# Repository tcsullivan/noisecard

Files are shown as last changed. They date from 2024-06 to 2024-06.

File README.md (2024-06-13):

# NoiseCard

NoiseCard is an attempt to build a dead easy tool for monitoring ambient noise levels. The ultra-low-power microcontroller takes periodic decibel measurements while powered on, using blinking LEDs for indication. The circuit requires only a few milliwatts to run, enabling it to run off of direct solar power without a battery (though some large capacitors provide a small reserve).

Ambient noise levels in populated areas, especially North America, can often exceed what is considered safe for our ears, with prolonged exposure leading to lasting impacts on our health. Through a tool like the NoiseCard, people can become more aware of the noisy environments they're living in (and potentially take action to reduce excess noise exposure).

## Building the source

You need:

* [ChibiOS sources](https://www.chibios.org/dokuwiki/doku.php)
* The arm-none-eabi GCC toolchain (through your distro or from [ARM developer](https://developer.arm.com/downloads/-/gnu-rm))
* [GNU Make](https://www.gnu.org/software/make/)
* [OpenOCD](https://openocd.org/) or another tool to program the microcontroller
* [KiCAD](https://www.kicad.org/) if you wish to work with the hardware files

Extract ChibiOS to a folder, edit the `Makefile` so CHIBIOS points to that folder, then run `make`.

### Flashing the card

You'll need a 6-pin Tag-Connect cable (e.g. [TC2030-CTX-NL](https://www.tag-connect.com/product/tc2030-ctx-nl-6-pin-no-legs-cable-with-10-pin-micro-connector-for-cortex-processors)), compatible programmer, and OpenOCD. Power up the card and run the following command (using the appropriate interface scripts for your programmer):

```
openocd -f interface/ftdi/olimex-arm-usb-ocd-h.cfg -f interface/ftdi/olimex-arm-jtag-swd.cfg -f target/stm32g0x.cfg -c "program build/ch.hex verify reset exit"
```

## Credits

* [ESP32-I2S-SLM](https://hackaday.io/project/166867-esp32-i2s-slm) for a starting point with accurate decibel-measuring code.
* [Qfplib](https://www.quinapalus.com/qfplib.html) for providing optimized floating-point code for the Cortex-M0+ microcontroller.
* ChibiOS for providing an awesome RTOS and HAL that made firmware porting and device configuration a breeze.

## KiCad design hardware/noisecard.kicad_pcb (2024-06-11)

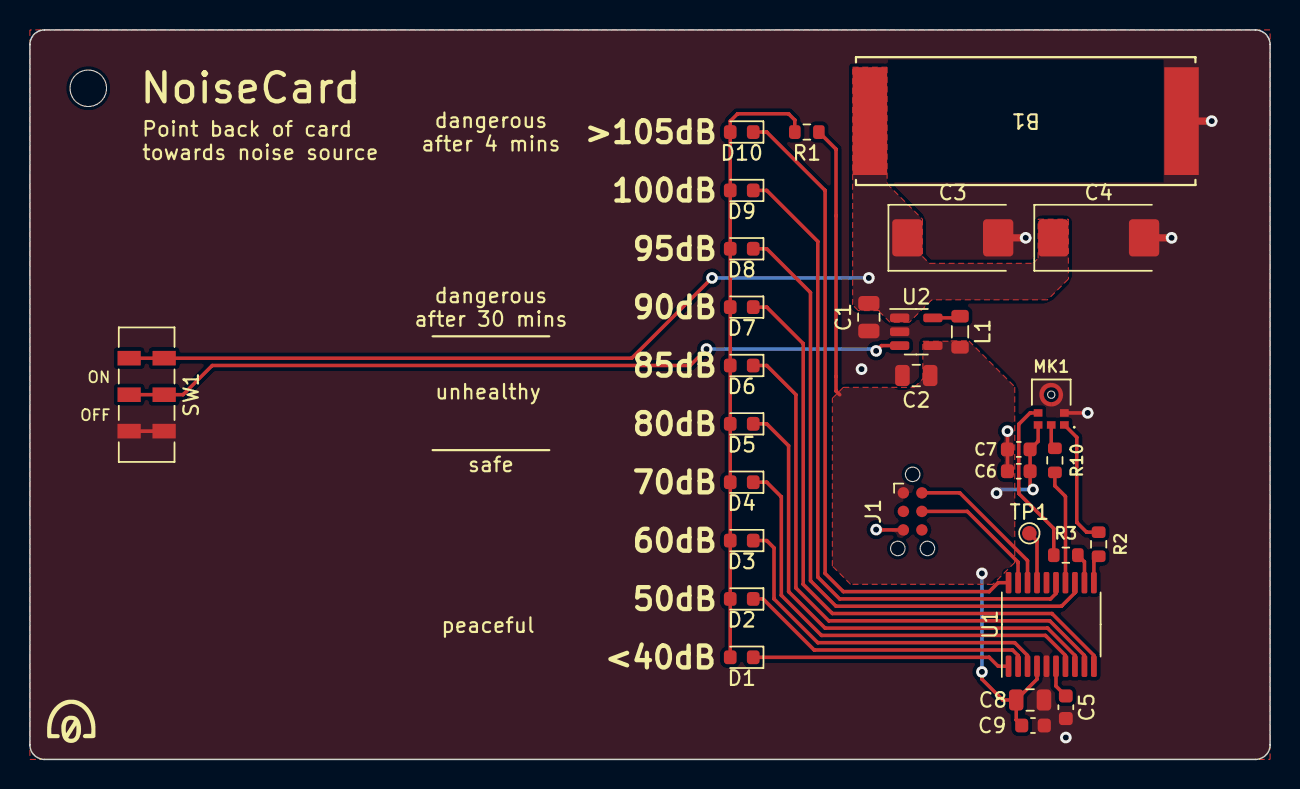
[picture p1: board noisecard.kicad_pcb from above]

Board: 2 copper layers, 85.0 x 50.0 mm, 32 parts (0 on the bottom side), 26 nets.

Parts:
B1: KXOB25-02X8F-TR; KXOB25-02X8F-TR_IXY
C1: 4u7; C_0805_2012Metric
C2: 10u; C_0805_2012Metric
C3, C4: 330u; CP_EIA-7343-15_Kemet-W
C5, C6, C9: 0.1U; C_0603_1608Metric
C7: 200P; C_0603_1608Metric
C8: 2U2; C_0805_2012Metric
D1, D2, D3, D4, D5, D6, D7, D8, D9, D10: LED; LED_0603_1608Metric
H1: MountingHole_Pad; MountingHole_2.5mm
J1: Conn_ARM_SWD_TagConnect_TC2030-NL; Tag-Connect_TC2030-IDC-NL_2x03_P1.27mm_Vertical
L1: 10u; L_0805_2012Metric
MK1: SPH0645LM4H-B; MIC_SPH0645LM4H-B
R1, R2, R3, R10: 51; R_0603_1608Metric
SW1: SW_DPDT_x2; SW_DPDT_CK_JS202011JCQN
TP1: TestPoint; TestPoint_Pad_D1.0mm
U1: STM32G031F6Px; TSSOP-20_4.4x6.5mm_P0.65mm
U2: LM3670MF; TSOT-23-5

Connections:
+1V8: C2.1, C6.1, C7.1, C8.1, C9.1, J1.1 (VCC), L1.2, MK1.5 (VDD), R1.1, U1.4 (VDD), U2.4 (FB)
EN: SW1.2 (B), SW1.5 (B), U2.3 (EN)
GND: B1.1, C1.2, C2.2, C3.2, C4.2, C5.2, C6.2, C7.2, C8.2, C9.2, J1.5 (GND), MK1.2 (SELECT), MK1.3 (GND), SW1.3 (C), SW1.6 (C), U1.5 (VSS), U2.2 (GND)
LED0: D1.1 (K), U1.1 (PB7/PB8)
LED1: D2.1 (K), U1.2 (PC14/PB9)
LED2: D3.1 (K), U1.3 (PC15)
LED3: D4.1 (K), U1.7 (PA0)
LED4: D5.1 (K), U1.8 (PA1)
LED5: D6.1 (K), U1.9 (PA2)
LED6: D7.1 (K), U1.10 (PA3)
LED7: D8.1 (K), U1.13 (PA6)
LED8: D9.1 (K), U1.15 (PB0/PB1/PB2/PA8)
LED9: D10.1 (K), U1.20 (PB3/PB4/PB5/PB6)
MIC_BCLK: MK1.4 (BCLK), R3.1
MIC_DATA_OUT: R10.2, U1.14 (PA7)
MIC_WS: MK1.1 (WS), R2.1
NRST: C5.1, U1.6 (PF2)
unnamed: D1.2 (A), D2.2 (A), D3.2 (A), D4.2 (A), D5.2 (A), D6.2 (A), D7.2 (A), D8.2 (A), D9.2 (A), D10.2 (A), R1.2
unnamed: MK1.6 (DATA_OUT), R10.1
unnamed: R2.2, U1.11 (PA4)
unnamed: R3.2, U1.12 (PA5)
unnamed: TP1.1, U1.17 (PA12/PA10)
unnamed: L1.1, U2.5 (SW)
SWCLK: J1.4 (SWCLK), U1.19 (PA14/PA15)
SWDIO: J1.2 (SWDIO), U1.18 (PA13)
VDC: B1.2, C1.1, C3.1, C4.1, SW1.1 (A), SW1.4 (A), U2.1 (Vin)

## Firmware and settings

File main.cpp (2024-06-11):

/**
 * Copyright (C) 2024  Clyne Sullivan <clyne@bitgloo.com>
 *
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
 * You should have received a copy of the GNU General Public License
 * along with this program.  If not, see <https://www.gnu.org/licenses/>.
 */
#include "hal.h"
#include "sos-iir-filter.h"

#include <algorithm>
#include <atomic>
#include <array>
#include <cstring>
#include <ranges>

static constexpr auto& WEIGHTING       = A_weighting;
static constexpr auto& MIC_EQUALIZER   = SPH0645LM4H_B_RB;
static constexpr sos_t MIC_OFFSET_DB   (  0.f); // Linear offset
static constexpr sos_t MIC_SENSITIVITY (-26.f); // dBFS value expected at MIC_REF_DB
static constexpr sos_t MIC_REF_DB      ( 94.f); // dB where sensitivity is specified
static constexpr sos_t MIC_OVERLOAD_DB (120.f); // dB - Acoustic overload point
static constexpr sos_t MIC_NOISE_DB    ( 29.f); // dB - Noise floor
static constexpr auto  MIC_BITS        = 18u;
static constexpr auto  SAMPLE_RATE     = 48000u;

static constexpr unsigned I2S_BUFSIZ = 1024;
static constexpr unsigned I2S_USESIZ = 16;

// Calculate reference amplitude value at compile time
static const auto MIC_REF_AMPL = sos_t((1 << (MIC_BITS - 1)) - 1) *
    qfp_fpow(10.f, MIC_SENSITIVITY / 20.f);

static std::atomic_bool i2sReady;
static std::array<uint32_t, I2S_BUFSIZ> i2sBuffer;
static sos_t Leq_sum_sqr (0.f);
static unsigned Leq_samples = 0;

static void blinkDb(int db);
static void i2sCallback(I2SDriver *i2s);

static constexpr unsigned I2SPRval = 16'000'000 / SAMPLE_RATE / 32 / 2;
static constexpr I2SConfig i2sConfig = {
    /* TX buffer */ NULL,
    /* RX buffer */ i2sBuffer.data(),
    /* Size */      i2sBuffer.size(),
    /* Callback */  i2sCallback,
    /* I2SCFGR */   (3 << SPI_I2SCFGR_I2SCFG_Pos) | // Master receive
                    (0 << SPI_I2SCFGR_I2SSTD_Pos) | // Philips I2S
                    (1 << SPI_I2SCFGR_DATLEN_Pos) | // 24-bit
                    SPI_I2SCFGR_CHLEN,              // 32-bit frame
    /* I2SPR */     (I2SPRval / 2) | ((I2SPRval & 1) ? SPI_I2SPR_ODD : 0)
};

int main(void)
{
    halInit();
    osalSysEnable();
  
    i2sReady.store(true);
    i2sStart(&I2SD1, &i2sConfig);
    i2sStartExchange(&I2SD1);
    // Microphone warmup time
    osalThreadSleepMilliseconds(140);
    // Reach filter delay steady state
    i2sReady.store(false);
    osalThreadSleepMilliseconds(120);
    // Discard initial readings
    Leq_sum_sqr = 0.f;
    Leq_samples = 0;

    for (;;) {
        i2sReady.store(false);
        SCB->SCR |= SCB_SCR_SLEEPONEXIT_Msk;
        //palClearLine(LINE_TP1);
        __WFI();
        //palSetLine(LINE_TP1);

        const auto sum_sqr = std::exchange(Leq_sum_sqr, sos_t(0.f));
        const auto count = std::exchange(Leq_samples, 0);
        const sos_t Leq_RMS = qfp_fsqrt(sum_sqr / qfp_uint2float(count));
        const sos_t Leq_dB = MIC_OFFSET_DB + MIC_REF_DB + sos_t(20.f) *
            qfp_flog10(Leq_RMS / MIC_REF_AMPL);
        const auto n = std::clamp(qfp_float2int(Leq_dB), 0, 999);
        blinkDb(n);
    }
}

void blinkDb(int db)
{
    auto line = LINE_LED0;

    if (db < 45)
        line = LINE_LED0;
    else if (db < 55)
        line = LINE_LED1;
    else if (db < 65)
        line = LINE_LED2;
    else if (db < 75)
        line = LINE_LED3;
    else if (db < 82)
        line = LINE_LED4;
    else if (db < 87)
        line = LINE_LED5;
    else if (db < 92)
        line = LINE_LED6;
    else if (db < 97)
        line = LINE_LED7;
    else if (db < 102)
        line = LINE_LED8;
    else
        line = LINE_LED9;

    palClearLine(line);
    osalThreadSleepMilliseconds(100);
    palSetLine(line);
}

__attribute__((section(".data")))
int32_t fixsample(uint32_t s) {
    return (int32_t)(((s & 0xFFFF) << 16) | (s >> 16)) >> (32 - MIC_BITS);
}

__attribute__((section(".data")))
void i2sCallback(I2SDriver *i2s)
{
    if (i2sReady.load())
        return;

    //palSetLine(LINE_TP1);

    const auto halfsize = i2sBuffer.size() / 2;
    const auto source = i2sBuffer.data() + (i2sIsBufferComplete(i2s) ? halfsize : 0);
    auto samples = reinterpret_cast<sos_t *>(source);
    std::ranges::copy(
        std::views::counted(source, I2S_USESIZ * 2)
            | std::ranges::views::stride(2)
            | std::views::transform([](uint32_t s) { return sos_t(qfp_int2float_asm(fixsample(s))); }),
        samples);
    auto samps = std::views::counted(samples, I2S_USESIZ);

    // Accumulate Leq sum
    MIC_EQUALIZER.filter(samps);
    Leq_sum_sqr += WEIGHTING.filter_sum_sqr(samps);
    Leq_samples += halfsize / 2;

    // Wakeup main thread for dB calculation every half second
    if (Leq_samples >= SAMPLE_RATE / 2) {
        i2sReady.store(true);
        SCB->SCR &= ~SCB_SCR_SLEEPONEXIT_Msk;
    }

    //palClearLine(LINE_TP1);
}

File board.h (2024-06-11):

/*
    ChibiOS - Copyright (C) 2006..2020 Giovanni Di Sirio

    Licensed under the Apache License, Version 2.0 (the "License");
    you may not use this file except in compliance with the License.
    You may obtain a copy of the License at

        http://www.apache.org/licenses/LICENSE-2.0

    Unless required by applicable law or agreed to in writing, software
    distributed under the License is distributed on an "AS IS" BASIS,
    WITHOUT WARRANTIES OR CONDITIONS OF ANY KIND, either express or implied.
    See the License for the specific language governing permissions and
    limitations under the License.
*/

#ifndef BOARD_H
#define BOARD_H

/*===========================================================================*/
/* Driver constants.                                                         */
/*===========================================================================*/

/*
 * Setup for STMicroelectronics STM32 Nucleo32-G031K8 board.
 */

/*
 * Board identifier.
 */
#define BOARD_ST_NUCLEO32_G031J6
#define BOARD_NAME                  "STMicroelectronics STM32 Nucleo32-G031J6"

/*
 * Board oscillators-related settings.
 * NOTE: HSE not fitted.
 */
#if !defined(STM32_LSECLK)
#define STM32_LSECLK                32768U
#endif

#define STM32_LSEDRV                (3U << 11U)

#if !defined(STM32_HSECLK)
#define STM32_HSECLK                0U
#endif

/*
 * MCU type as defined in the ST header.
 */
#define STM32G031xx

/*
 * IO lines assignments.
 */
#define LINE_I2S_SD                 PAL_LINE(GPIOA, 7U)
#define LINE_I2S_WS                 PAL_LINE(GPIOA, 4U)
#define LINE_I2S_CK                 PAL_LINE(GPIOA, 5U)

#define LINE_TP1                    PAL_LINE(GPIOA, 12U)

#define LINE_LED0                   PAL_LINE(GPIOB, 7U)
#define LINE_LED1                   PAL_LINE(GPIOC, 14U)
#define LINE_LED2                   PAL_LINE(GPIOC, 15U)
#define LINE_LED3                   PAL_LINE(GPIOA, 0U)
#define LINE_LED4                   PAL_LINE(GPIOA, 1U)
#define LINE_LED5                   PAL_LINE(GPIOA, 2U)
#define LINE_LED6                   PAL_LINE(GPIOA, 3U)
#define LINE_LED7                   PAL_LINE(GPIOA, 6U)
#define LINE_LED8                   PAL_LINE(GPIOB, 0U)
#define LINE_LED9                   PAL_LINE(GPIOB, 3U)

/*
 * I/O ports initial setup, this configuration is established soon after reset
 * in the initialization code.
 * Please refer to the STM32 Reference Manual for details.
 */
#define PIN_MODE_INPUT(n)           (0U << ((n) * 2U))
#define PIN_MODE_OUTPUT(n)          (1U << ((n) * 2U))
#define PIN_MODE_ALTERNATE(n)       (2U << ((n) * 2U))
#define PIN_MODE_ANALOG(n)          (3U << ((n) * 2U))
#define PIN_ODR_LOW(n)              (0U << (n))
#define PIN_ODR_HIGH(n)             (1U << (n))
#define PIN_OTYPE_PUSHPULL(n)       (0U << (n))
#define PIN_OTYPE_OPENDRAIN(n)      (1U << (n))
#define PIN_OSPEED_VERYLOW(n)       (0U << ((n) * 2U))
#define PIN_OSPEED_LOW(n)           (1U << ((n) * 2U))
#define PIN_OSPEED_MEDIUM(n)        (2U << ((n) * 2U))
#define PIN_OSPEED_HIGH(n)          (3U << ((n) * 2U))
#define PIN_PUPDR_FLOATING(n)       (0U << ((n) * 2U))
#define PIN_PUPDR_PULLUP(n)         (1U << ((n) * 2U))
#define PIN_PUPDR_PULLDOWN(n)       (2U << ((n) * 2U))
#define PIN_AFIO_AF(n, v)           ((v) << (((n) % 8U) * 4U))

/*===========================================================================*/
/* External declarations.                                                    */
/*===========================================================================*/

#if !defined(_FROM_ASM_)
#ifdef __cplusplus
extern "C" {
#endif
  void boardInit(void);
#ifdef __cplusplus
}
#endif
#endif /* _FROM_ASM_ */

#endif /* BOARD_H */

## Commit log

2024-06-02 use qfplib; fix I2S clock
    [main.cpp, mcuconf.h]
2024-06-05 fix qfplib dependence; clean up filter()
    [main.cpp]
2024-06-05 add hardware files
    [noisecard.kicad_pcb, noisecard.kicad_sch]
2024-06-07 go os-less; filter in sram; consider dynamic freq
2024-06-08 wip: prep code for brief execution
    we do *not* have much power available
2024-06-10 schematic cleanup
    [noisecard.kicad_pcb, noisecard.kicad_sch]
2024-06-10 pcb firmware working
2024-06-10 move io config to board.c
2024-06-11 make led show a little longer

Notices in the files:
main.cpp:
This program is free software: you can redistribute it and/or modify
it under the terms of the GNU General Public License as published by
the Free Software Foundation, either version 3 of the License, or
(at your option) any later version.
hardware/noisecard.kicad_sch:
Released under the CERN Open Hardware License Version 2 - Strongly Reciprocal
